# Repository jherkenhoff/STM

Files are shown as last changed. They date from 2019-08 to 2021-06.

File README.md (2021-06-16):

# Scanning tunneling microscope

# Table of Contents
- [Mechanics](#mechanics)
  - [Vibration Isolation](#vibration-isolation)
    - [Characterization Measurements](#vibration-characterization-measurements)
  - [Piezo Scanner](#piezo-scanner)
  - [Scan Head Assembly](#scan-head-assembly)
- [Electronics](#electronics)
  - [Power Supply](#power-supply)
  - [Mainboard](#mainboard)
  - [Tunneling Amp](#tunneling-amp)
  - [Base and Head Interconnect](#interconnects)
- [Software](#software)
  - [PRU Firmware](#pru-firmware)
  - [Kernel Driver](#kernel-driver)
  - [Webapp](#webapp)
    - [Backend](#backend)
    - [Frontend](#frontend)
- [References](#references)

# Mechanics

### Vibration Isolation

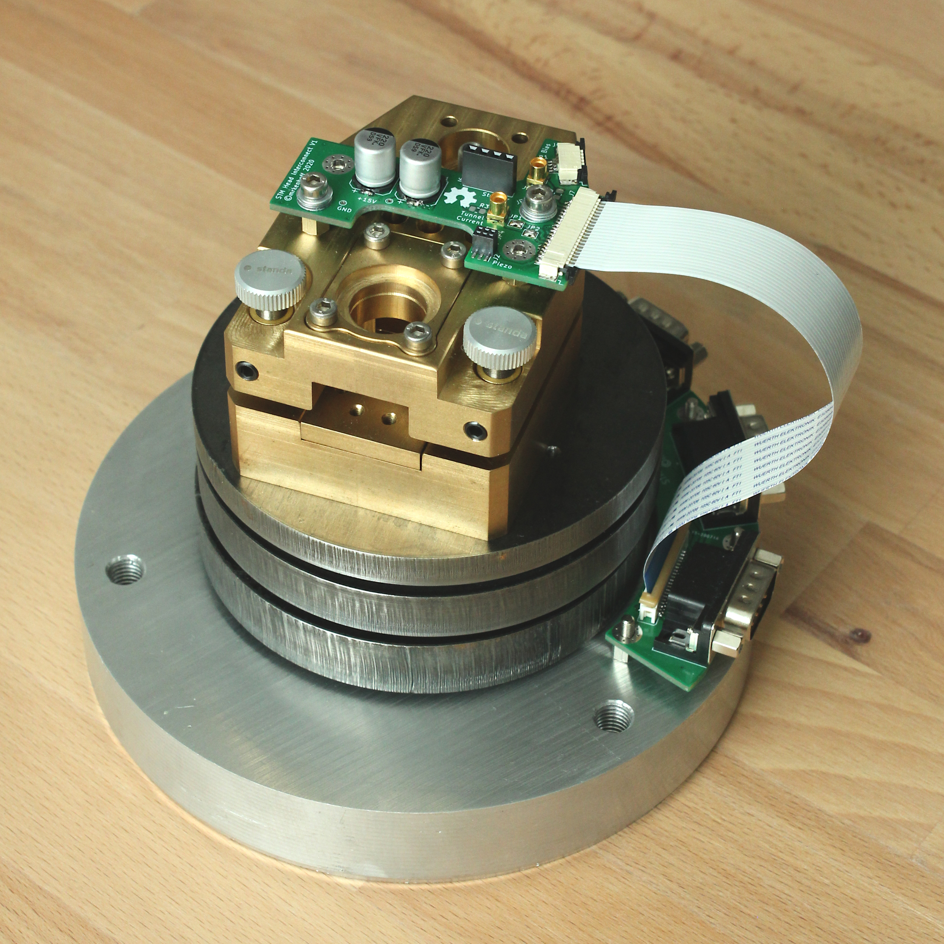
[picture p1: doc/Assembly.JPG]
STM Assembly


Mechanical vibrations present a major difficulty in scanning probe microscopy, as they can interfere with the very small (resolutions of a few 0.1 nm are not uncommon [1]) scanning movements of the tip, leading to a distorted image. Even worse, large mechanical vibrations can cause the scanning tip, which is usually positioned only a few Angstrom above the sample surface [2], to crash into the sample.

Unfortunately, there are many sources for mechanical vibrations: Driving cars, peoples walking around, wind blowing on the walls of your house and the subtle, but omnipresent seismic activity of the earth, just to name a few.
Especially since I'm living in a big City, good isolation of vibrations from the scanning head was essential for this build.
To accomplish this, I used a stack of steel plates, separated using pieces of Viton o-rings.
Viton was used, as it is reported to have a high damping coefficient, making it particularly usefull for vibration isolation [3]. This tower of heavy masses and Viton "springs/dampers" can be described as a set of coupled harmonic oscillators, which (if tuned correctly) provide an efficient way of decoupling mechanical vibrations. The vibration isolation should be designed to have the smallest possible resonance frequency (usually in the range of a couple Hz [*todo: citation*]), resulting in the desired attenuation of vibrations in the higher frequency range. The scanning head itself, which is mounted on the topmost steel plate, is designed to have the largest possible resonance frequency. This will guarantee, that any low frequency component that couple through the vibration isolation assembly will only shake the scanning head as a whole, and not influence the relative position between the tip and the probe surface.

The figure above depicts an aluminium baseplate (150 mm diameter, 25 mm thickness), the stack of steel plates and viton o-rings, and the scanning head. The steel plates have a diameter of 100 mm and have an decreasing thickness of 15 mm, 12 mm and 8 mm towards the top. I do have some spare plates lying around, so I will definately try out some other configurations as well. The plates are lasercut - hence the terrible surface finish. I might clean them up on a lathe if I can get my hands on one at some point...
The complete depicted assembly can optionally be hung from some kind of support structure using steel springs or elastic rope to add another stage of vibration isolation. Since the baseplate is made of aluminium, additional eddy-current damping can be applied if needed.

#### Characterization Measurements
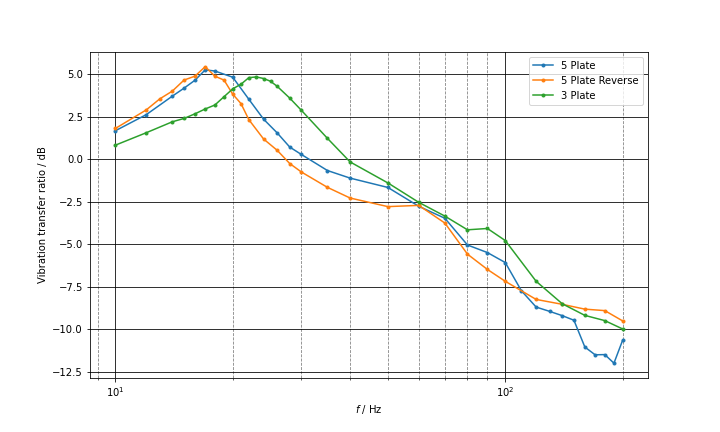
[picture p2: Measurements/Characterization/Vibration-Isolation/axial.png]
Axial vibration isolation measurement


### Piezo Scanner
Most professional scanning tunneling microscopes make use of piezo tube scanners. Due to their high rigidity (high resonance frequency) and exceptional linearity they are ideally suited for that task. Unfortunately they can cost up to several hundred euros and it's not easy to find a distributor who sells these things to individuals in the first place.

Fortunately, there is an alternative for the expensive piezo tube scanners: Flat piezo disks, commonly used as acoustic transducers in all kinds of electronic devices, can be modified to provide the desired x/y/z scanning motion. For that, the top electrode of the piezo must be cut into four segments, which will be individually controlled using four control voltages. A small standoff is glued to the bottom side of the piezo disk, to which the scanning probe tip is attached.
Depending on the applied voltages, the piezo disk will bend and warp, resulting in a translation of the scanning probe tip.
The idea and the first successfull realization for this "unimorph disk scanner" was published by John Alexander in his great STM Project.
Since then, this approach has been successfully used in numerous other low-cost STM projects, as these devices are really cheap (less than 1€ per part) and sold by all major electronics distributors.
The downside of this approach is its low mechanical rigidity, resulting in a lower resonance frequency compared to professional piezo tube scanners. Therefore the achievable scan speed is somewhat limited and the piezo scanner is more sensitive to mechanical vibrations.
These are limitations I am willing to accept, as it saves me a lot of money, while still providing great results.

I used a 20 mm piezo disk and carefully cut the upper electrode into four segments using a scalpel. The upper electrode is commonly made of deposited silver which can be scraped off with medium force. However, care must be taken not to cut/scrape too deep into the piezo crystal itself, as it might get damaged.
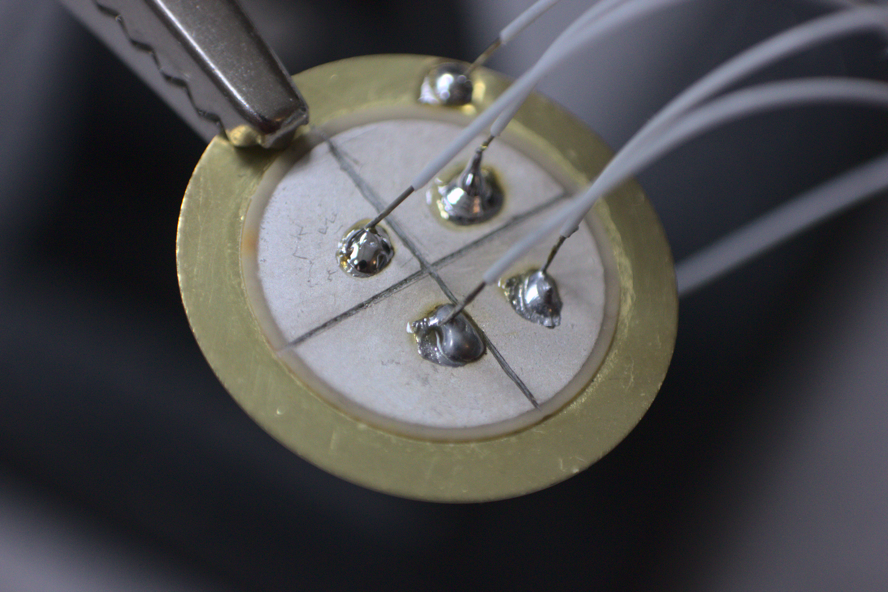
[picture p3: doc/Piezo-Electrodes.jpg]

I attached thin enameled copper wires to the electrodes ~~using conducting epoxy (MG Chemicals 9410)~~ using solder. Tthere is the risk of depolarizing the piezo crystal when applying too much heat, but luckily my piezo survived. The copper wires are attached to a miniature 2x6 pin header, which connects to the head interconnect PCB.

A 10mm ceramic standoff (Essentra Components CER-3) is glued to the bottom of the piezo element, translating the "warping motion" of the flat piezo disk into a translational motion of the scanning probe tip, which in turn is inserted into a precision pin socket glued to the other side of the ceramic standof. Ceramic was chosen for its very high resistivity, resulting in low leakage of the tunneling current.
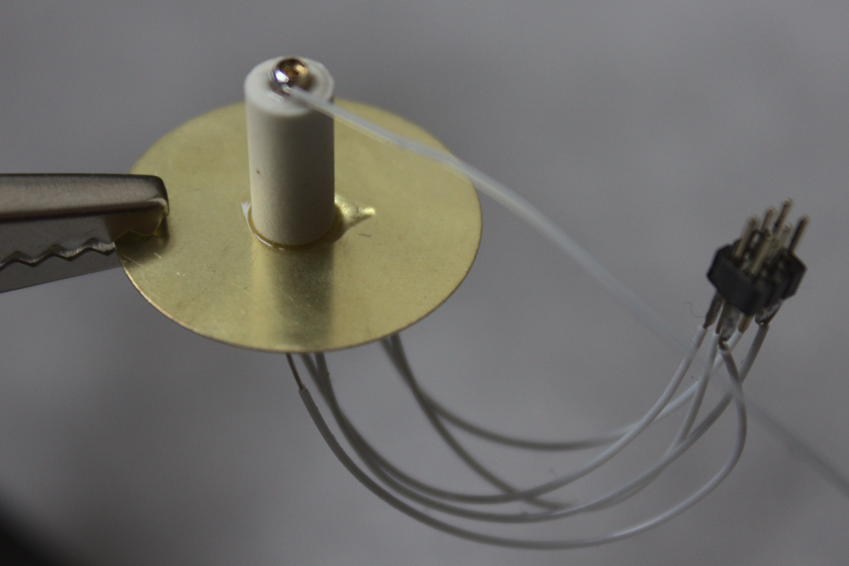
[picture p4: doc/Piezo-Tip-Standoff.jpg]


The piezo disk is placed in a brass mounting plate and is held down using a small 3D printed plate when screwed into the scanning head. I decided against mounting the piezo directly onto the scanning head in order to stay flexible and be able to experiment with different piezo scanners, by simply swapping out the whole brass-plate assembly.
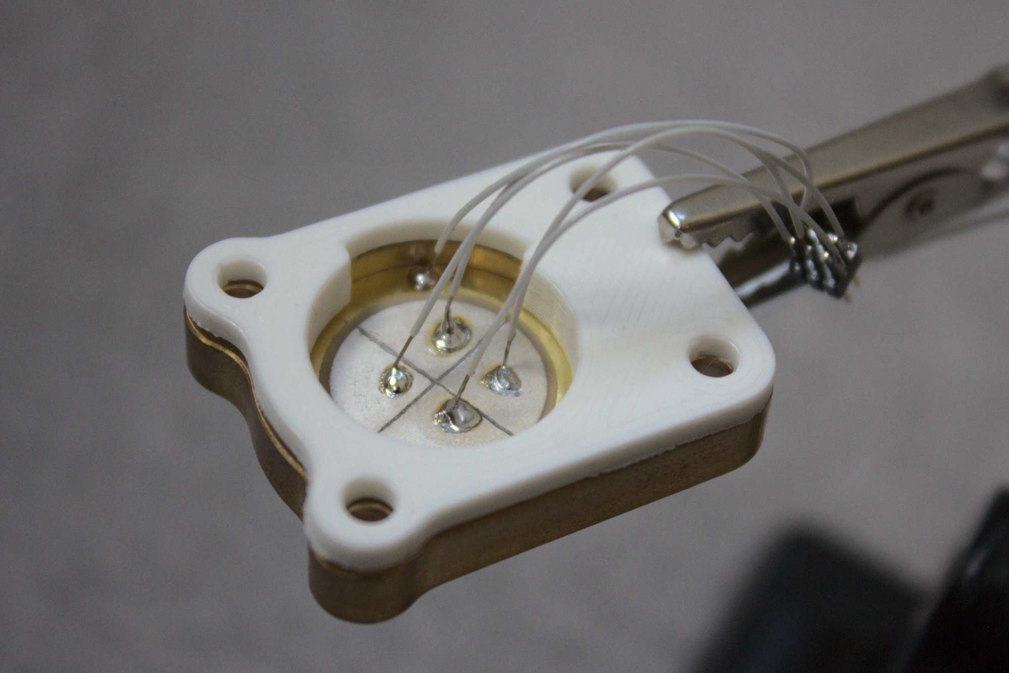
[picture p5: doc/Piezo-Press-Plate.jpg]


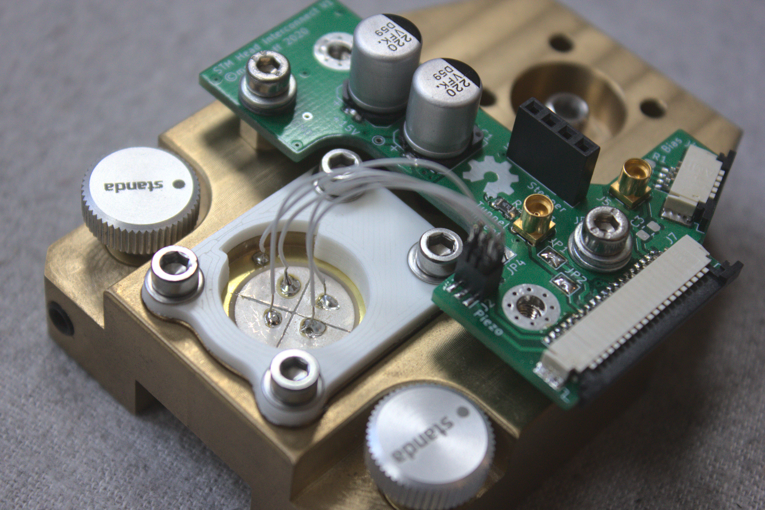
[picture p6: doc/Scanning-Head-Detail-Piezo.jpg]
Scanning head assembly


### Scan Head Assembly
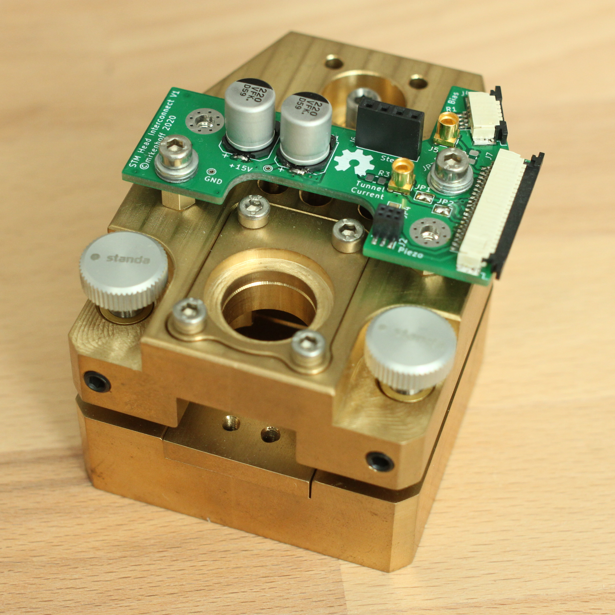
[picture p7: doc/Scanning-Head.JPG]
Scanning head assembly


The scan head assembly is the central piece of the STM. It's the place where the piezo scanner, including the scanning probe tip, and the material to be imaged are mounted and brought together, and thus contributes directly the achievable image quality.

All parts of the scan head assembly have been machined out of brass using a CNC mill. The choice of material is

- Lowest possible thermal expansion coefficient to reduce gradient artifacts due to thermal fluctuations.
- Highest possible stiffness in order to achieve a high mechanical resonance frequency of the scan head assembly.
- The material must not cost a fortune and should be relatively easy to machine without highly specializied equipment.

# Electronics
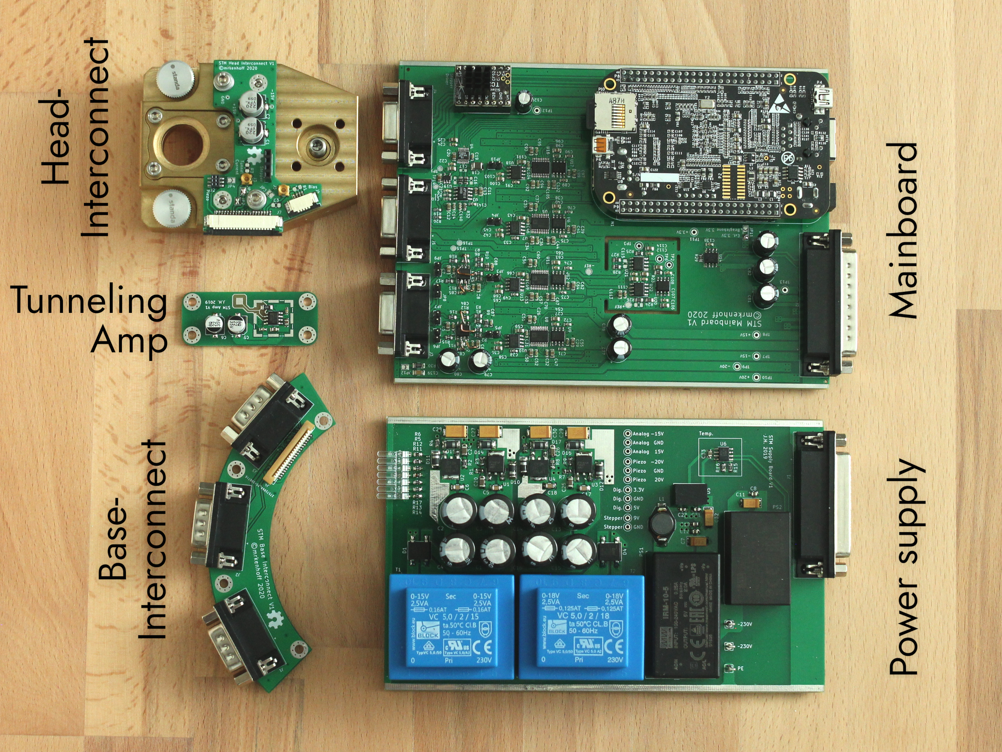
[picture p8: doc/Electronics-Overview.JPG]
Electronics overview


### Power Supply

- **Analog +/- 15 V:** Supply for DACs, ADC and tunneling amp
- **Piezo +/- 20 V:** Supply for piezo driver amplifiers
- **Digital 5 V:** Beaglebone supply
- **Digital 3.3 V:** Digital interfaces (DACs, ADC) and supply for temperature sensor
- **Stepper 9 V:** Supply for stepper motor driver

### Mainboard

### Tunneling Amp

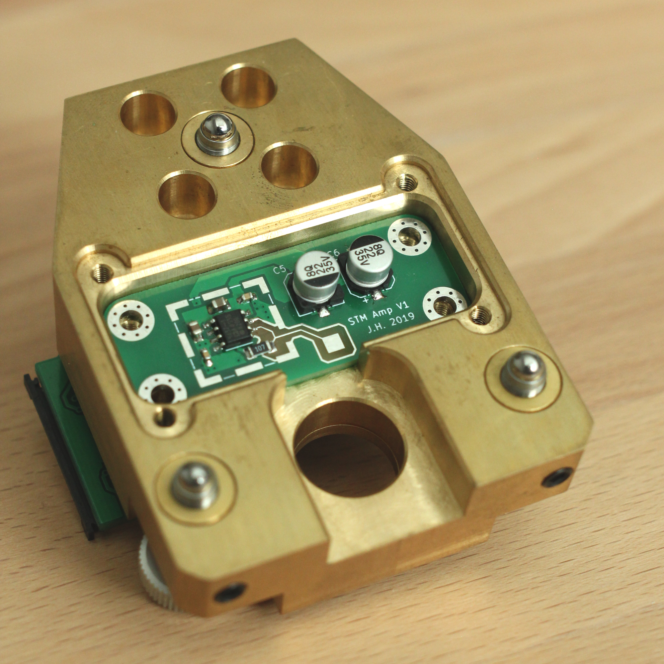
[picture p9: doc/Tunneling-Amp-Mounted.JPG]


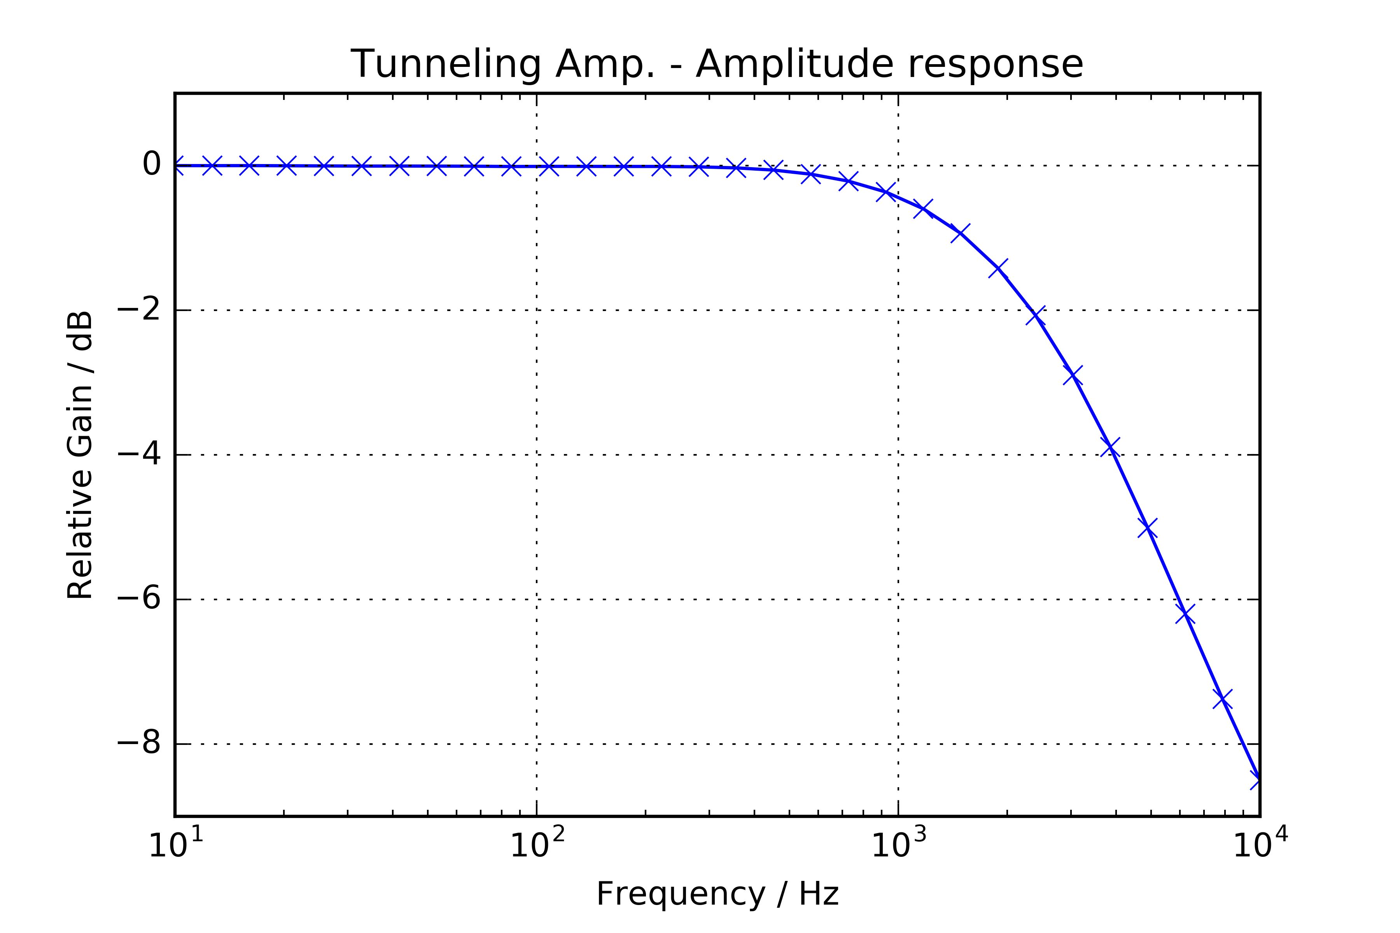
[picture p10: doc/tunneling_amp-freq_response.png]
tunneling-amp-freq-response


### Base and Head Interconnect

# Software

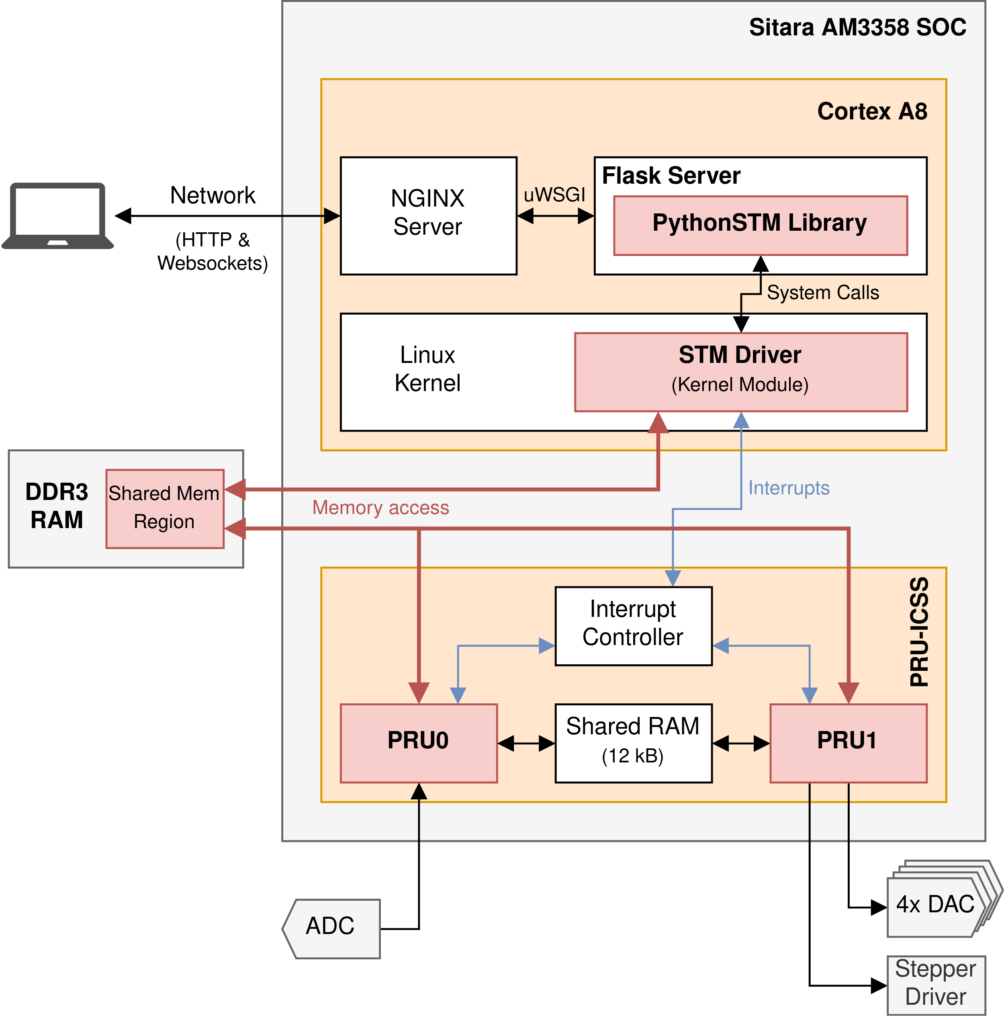
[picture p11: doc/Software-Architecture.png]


### PRU Firmware
### Kernel Driver
### Webapp
#### Backend
#### Frontend

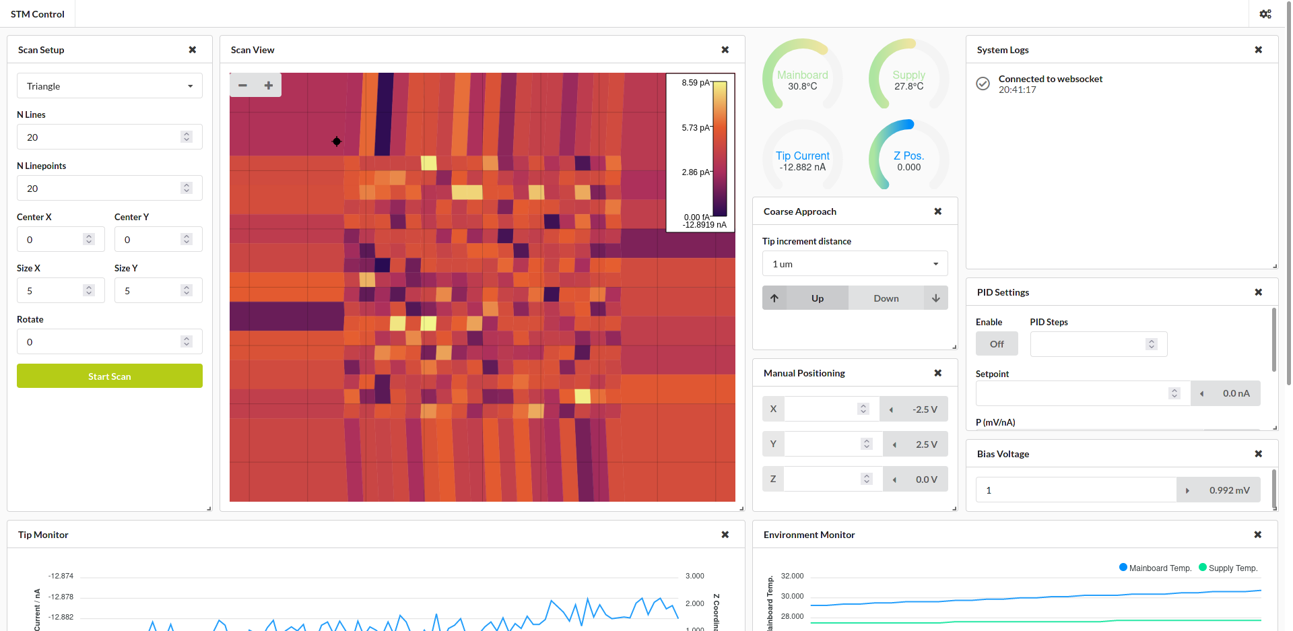
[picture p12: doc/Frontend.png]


# References

- [1] C. Bai (2000). Scanning tunneling microscopy and its applications. New York: Springer Verlag. ISBN 978-3-540-65715-6.
- [2] C. Julian Chen (1993). Introduction to Scanning Tunneling Microscopy (PDF). Oxford University Press. ISBN 978-0-19-507150-4.
- [3] Oliva, Ai & Aguilar, Marilyn & Sosa, Victor. (1999). Low- and high-frequency vibration isolation for scanning probe microscopy. Measurement Science and Technology. 9. 383. 10.1088/0957-0233/9/3/011.

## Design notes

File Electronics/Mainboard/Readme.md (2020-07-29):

## Changes for version 2:

- Correct polarity of electrolyte capacitors
- Remove pin DAC_MISO (Fails to boot: https://github.com/beagleboard/beaglebone-black/wiki/System-Reference-Manual#boot-configuration)
- Change + and - Pins of Z+X / Z-X / Z+Y / Z-Y OP Amps

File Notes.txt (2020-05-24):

# ADC Selection

Architecture: SAR, because Delta-Sigma has a large latency ->  Bad control loop behaviour

# Supply

+/- 15V Tunneling Amp and Analog Circuitry
        10 mA Tunneling Amp
+/- 20V Piezo driver
5V/3,3V Digital supply
???     Stepper driver voltage

LM75 Temperature Sensors
  - One near the transformators
  - One near the regulators
  - ADC Board
  - DAC Board
  - DAC Board OP section

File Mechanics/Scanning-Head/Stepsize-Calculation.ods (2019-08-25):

Step angle | 1.8 | °
Gear ratio | 27
Screw pitch | 0.24 | mm/rev
Lever ratio | 16
Tip step size | 2.77777777777778 | nm/step

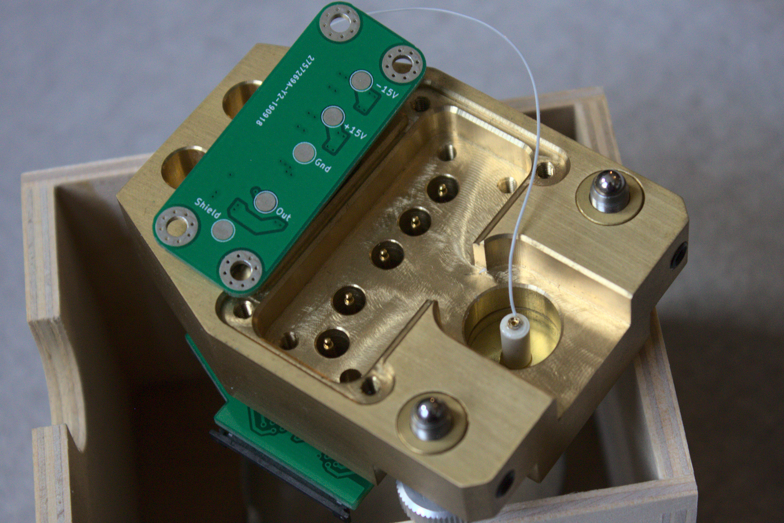
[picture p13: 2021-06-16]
doc/Scanning-Head-Amp.jpg

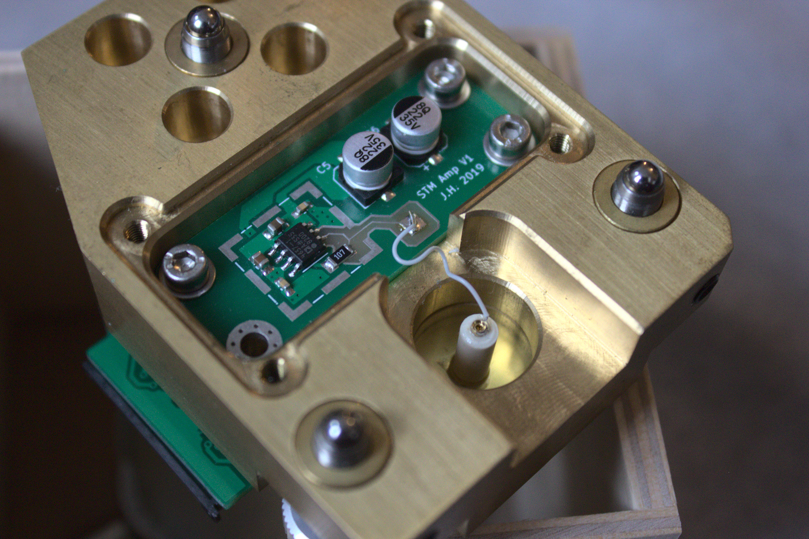
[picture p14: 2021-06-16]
doc/Scanning-Head-Amp-Mounted.jpg

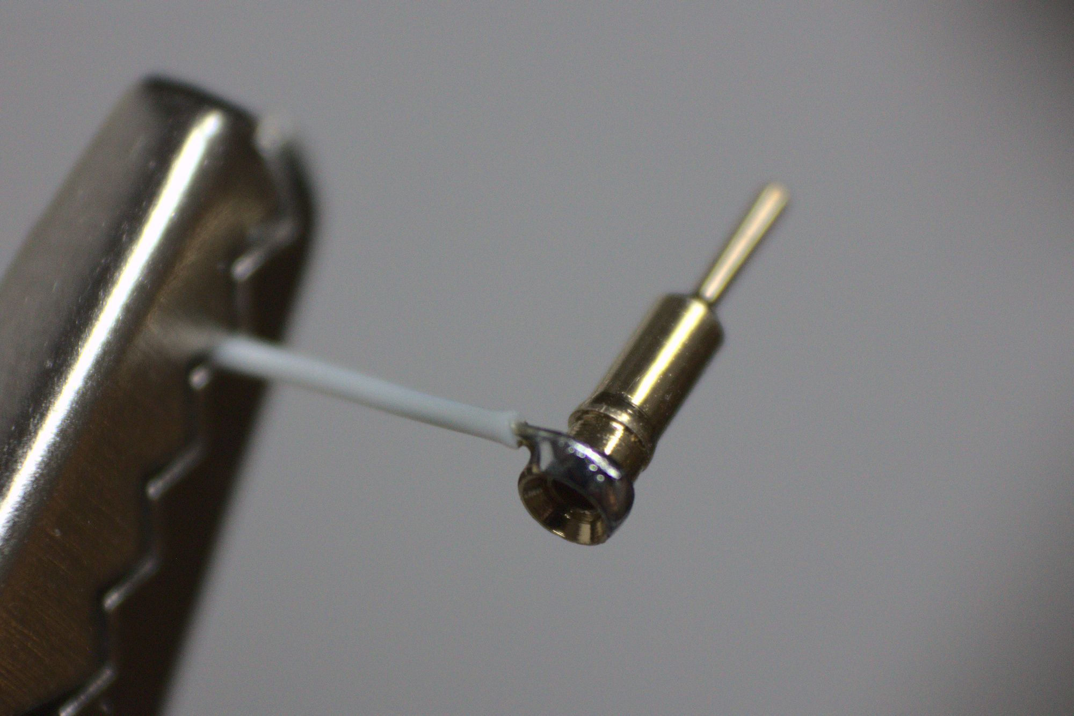
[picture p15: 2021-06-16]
doc/Pin-Socket.jpg

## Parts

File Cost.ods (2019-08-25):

Bezeichnung | Anzahl | Einzelpreis | Versandkosten | Gesamt
Mechanik
Schrittmotor | 1 | 34.75 | 4 | 38.75
Einstellschrauben | 1 | 68 | 0 | 68
Messing | 1 | 30 | 10 | 40
Aluminium | 1 | 20 | 0 | 20
Plastik | 1 | 15 | 0 | 15
Stahl | 1 |  |  | 0
Viton | 1 | 14 | 0 | 14
 |  |  |  | 0
 |  |  |  | 0
Elektronik
Piezo | 3 | 3 | 0 | 9
Tunnel OPA | 2 | 10 | 0 | 20
DAC | 5 | 10 | 0 | 50
ADC | 1 | 15 | 0 | 15
 |  |  |  | 0
 |  |  |  | 0
 |  |  |  | 0
PCBs | 1 | 20 | 6 | 26
 |  |  |  | 0
 |  |  |  | 0
 |  |  | Gesamt | 315.75

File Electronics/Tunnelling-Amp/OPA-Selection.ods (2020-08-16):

Hersteller | Typ | Input bias |  | GBW | Voltage Noise | Current Noise | Offset Voltage (Typ) |  | In. Volt. Drift | Supply | Preis
 |  | pA | pA | MHz | nV/√Hz | fA/√Hz | µV |  | µV / °C | V | EUR
 |  | 25°C | Tmin – Tmax |  | 1 kHz |  | 25°C | Tmin – Tmax
TI | LMC6081AI | 0.01 | 4 | 1.3 | 22 |  | 350 | 800 | 1 | 16 | 2.5
TI | LMC6001 | 0.01 | 2 | 1.3 | 22 |  | 700 | 1000 | 2.5 | 16 | 15
AD | ADA4637-1B | 1 | 2000 | 80 | 6 | 1.6 | 200 | 400 | 1 | 36 | 10
TI | OPA602BP | 1 | 20 | 6.2 | 13 | 0.6 | 500 | 750 | 3 | 36 | 15 | Nur DIP!
 | OPA637AP | 2 | 2000 | 80 | 5.6 | 2.5 | 280 | / | 2.5 | 36 | 23
 | OPA637BP | 1 | 1000 | 80 | 5.2 | 1.6 | 100 | / | 0.8 | 36 | 30
 | OPA124UA | 0.5 | 2 |  | 8 | 0.5 | 150 | 500 | 2 | 36 | 11
 | ADA4530-1 | 0.02 | 0.25 | 2 | 16 | 0.07 | 8 | 300 | 0.13 | 16 | 22
 | OPA828 | 1 | 400 | 45 | 4 | 1.2 | 50 | 400 | 0.3 | 40 | 7
 | OPA129 | 0.03 | 30 | 1 | 17 | 0.1 | 500
 |  |  |  |  |  | GBW | 80 | MHz
 |  |  |  |  |  | R | 100 | Mohm
 |  |  |  |  |  | C | 10 | pF
 |  |  |  |  |  | Bandwidth | 112.8 | kHz
 |  |  |  |  |  | Quelle: | http://www.ti.com/lit/an/sboa122/sboa122.pdf

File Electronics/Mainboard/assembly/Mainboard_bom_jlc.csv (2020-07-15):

Comment | Designator | Footprint | LCSC Part #
2u2 | C20,C21 | C_0805_2012Metric_Pad1.15x1.40mm_HandSolder | C49217
220p | C83,C84,C85,C86,C88,C87 | C_0603_1608Metric_Pad1.05x0.95mm_HandSolder | C1603
10p | C91,C89,C90,C49,C73,C74,C33,C75,C76,C28,C71,C72 | C_0603_1608Metric_Pad1.05x0.95mm_HandSolder | C1634
10u | C106,C109,C118,C119,C113,C114,C102,C92,C93,C96,C97,C100,C101,C5,C6,C7,C8,C67,C53,C56,C61,C62,C65,C66,C44,C34,C35,C38,C39,C42,C43,C47,C50,C51,C54,C55,C58,C59,C11,C12,C25,C23 | C_0805_2012Metric_Pad1.15x1.40mm_HandSolder | C15850
100n | C138,C108,C107,C111,C112,C117,C116,C94,C95,C99,C98,C103,C104,C105,C1,C2,C3,C4,C57,C60,C64,C63,C68,C69,C70,C36,C37,C41,C40,C45,C46,C48,C52,C26,C29,C27,C30,C31,C32,C13,C14,C19,C22,C24 | C_0603_1608Metric_Pad1.05x0.95mm_HandSolder | C14663
100n | C139 | C_1206_3216Metric_Pad1.42x1.75mm_HandSolder | C24497
1n | C140,C9 | C_0603_1608Metric_Pad1.05x0.95mm_HandSolder | C1588
680p | C141,C10 | C_0603_1608Metric_Pad1.05x0.95mm_HandSolder | C1630
3k3 | R13,R14,R7,R8,R5,R6,R10,R1,R2,R11,R12,R3,R4,R9 | R_0805_2012Metric | C26010
49R9 | R18,R17,R16,R15 | R_0805_2012Metric | C17720
560R | R19,R20 | R_0603_1608Metric_Pad1.05x0.95mm_HandSolder | C23204
0R | R22,R21 | R_0805_2012Metric | C17477
1k | R23,R24,R26,R25,R27,R28 | R_0805_2012Metric | C17513
4k7 | R29 | R_0805_2012Metric | C17673
1M2 | R30 | R_1206_3216Metric_Pad1.42x1.75mm_HandSolder | C22107
1k | R32,R31 | R_0603_1608Metric_Pad1.05x0.95mm_HandSolder | C21190

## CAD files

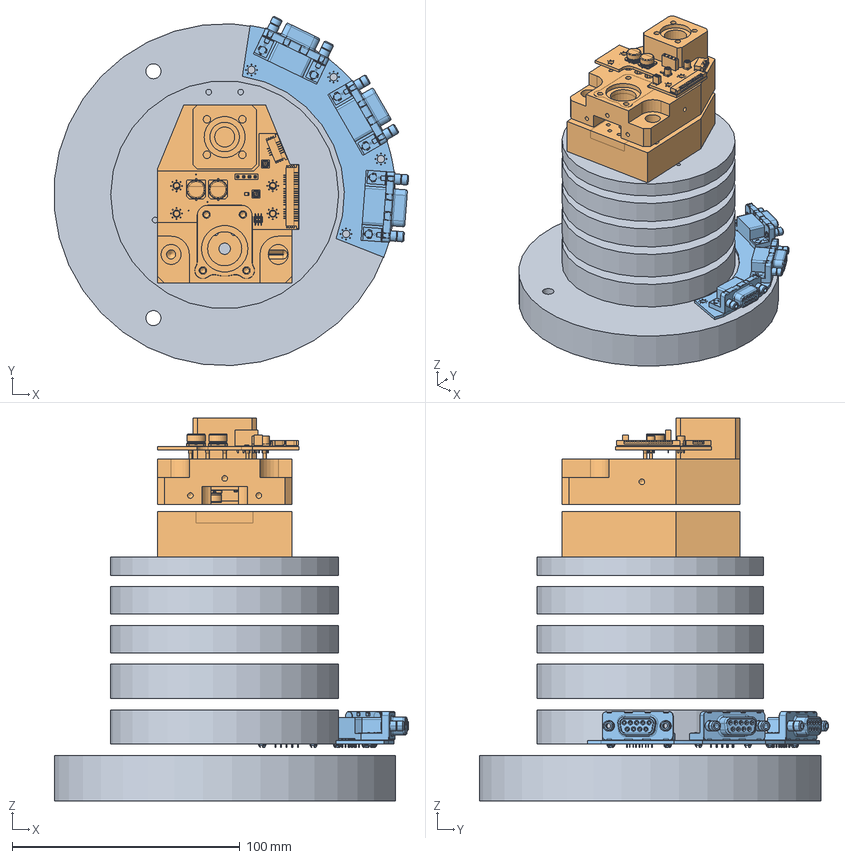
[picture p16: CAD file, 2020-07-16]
Mechanics/Assembly.FCStd
155.4 x 153.1 x 168.0 mm
Vibration-Isolation_001
Scanning-Head-Assembly_001
Base-Interconnect1_001

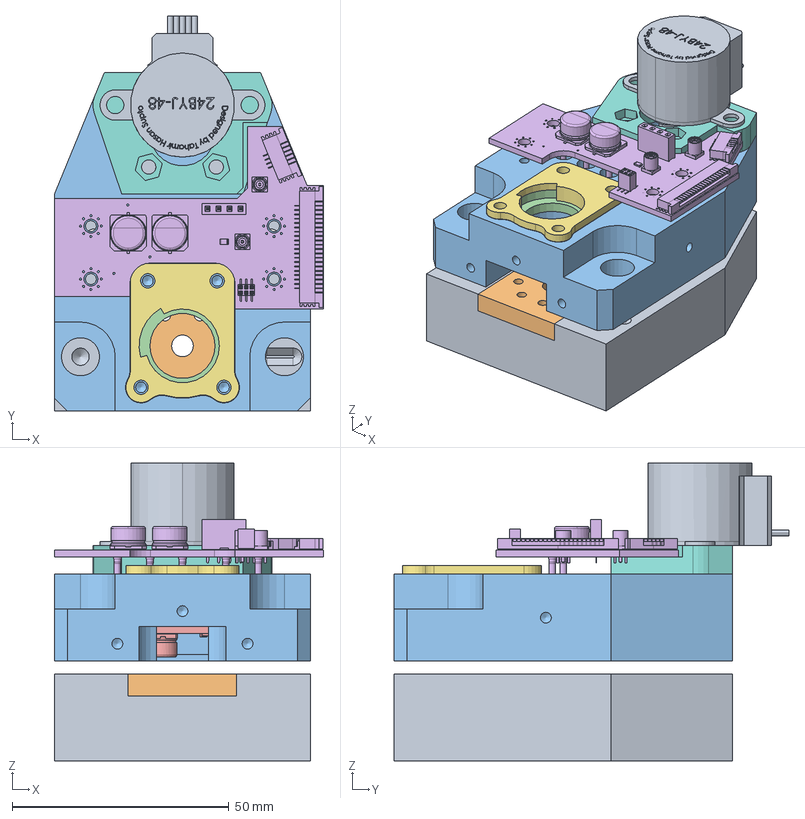
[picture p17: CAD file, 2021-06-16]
Mechanics/Scanning-Head/Scanning-Head-Assembly.FCStd
62.0 x 91.0 x 68.6 mm
Lower-Plate_001
Probe-Holder_001
Upper-Plate_001
Tip-Holder_001
Tunnelling-Amp1_001
Head-Interconnect1_001
Piezo-Press-Plate_001
Motor-Adapter_001
stepper-24BYJ-481_001

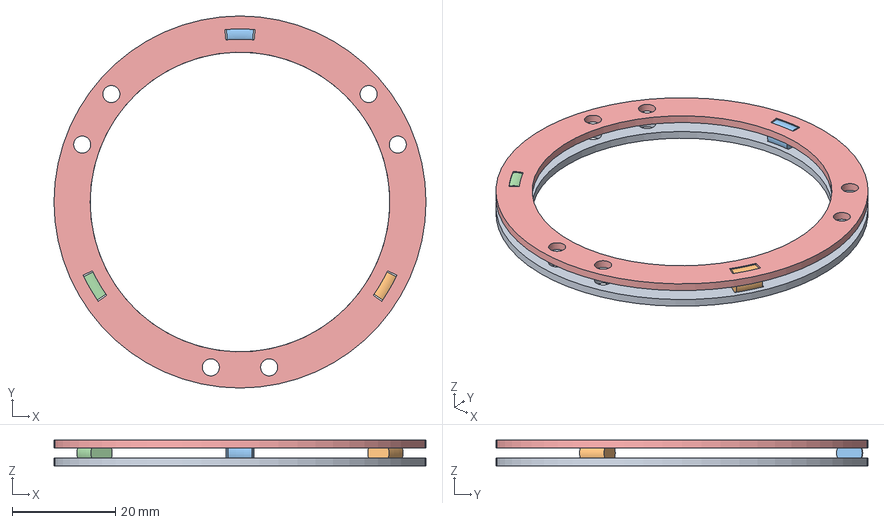
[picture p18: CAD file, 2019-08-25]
Mechanics/Vibration-Isolation/Viton-Assembly.FCStd
72.0 x 72.0 x 5.00 mm
Viton-Fixture_001
Viton_001
Viton_002
Viton_003
Viton-Fixture_002

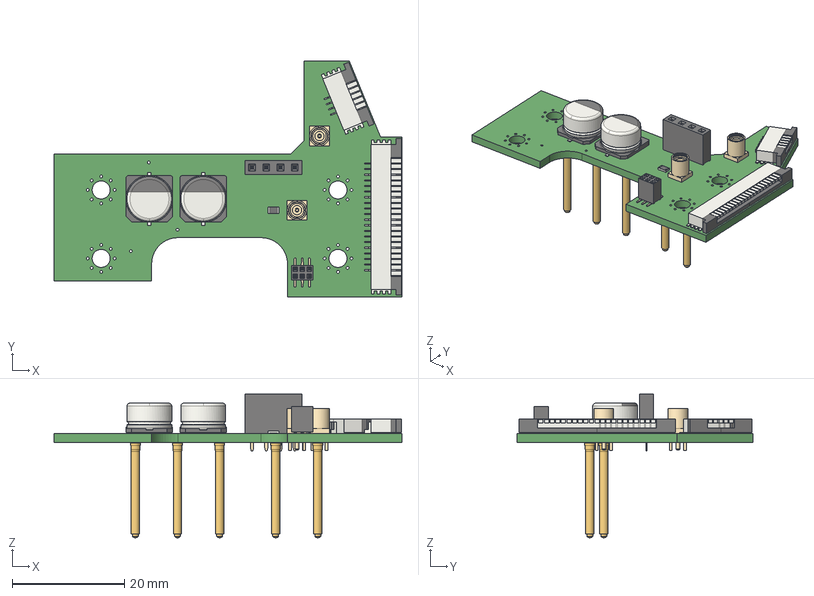
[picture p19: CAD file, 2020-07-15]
Electronics/Head-Interconnect/Head-Interconnect.step
62.0 x 42.1 x 25.6 mm

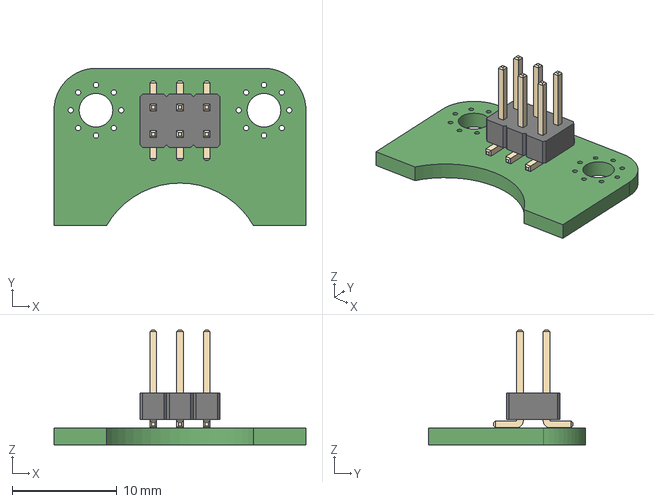
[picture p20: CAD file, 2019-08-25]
Electronics/Piezo-Connector/Piezo-Connector.step
24.0 x 15.0 x 11.0 mm

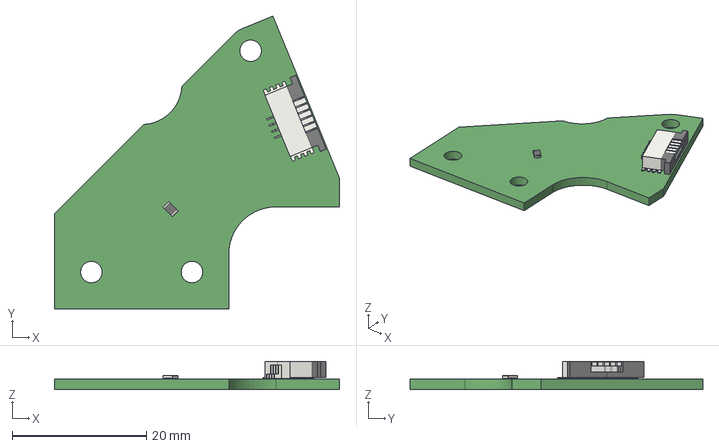
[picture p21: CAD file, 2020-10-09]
Electronics/Sample-Bias-Interconnect/Sample-Bias-Interconnect.step
42.5 x 43.7 x 4.21 mm

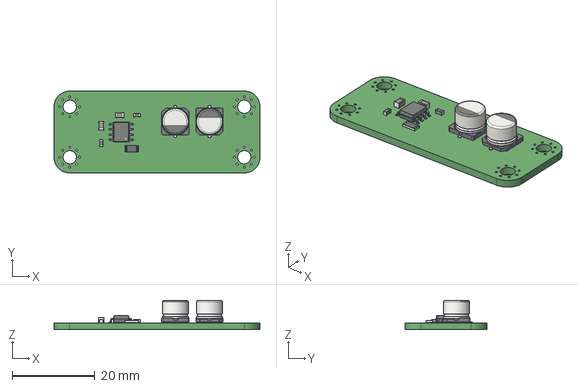
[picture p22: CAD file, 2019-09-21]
Electronics/Tunnelling-Amp/Tunnelling-Amp.step
49.8 x 19.8 x 7.05 mm

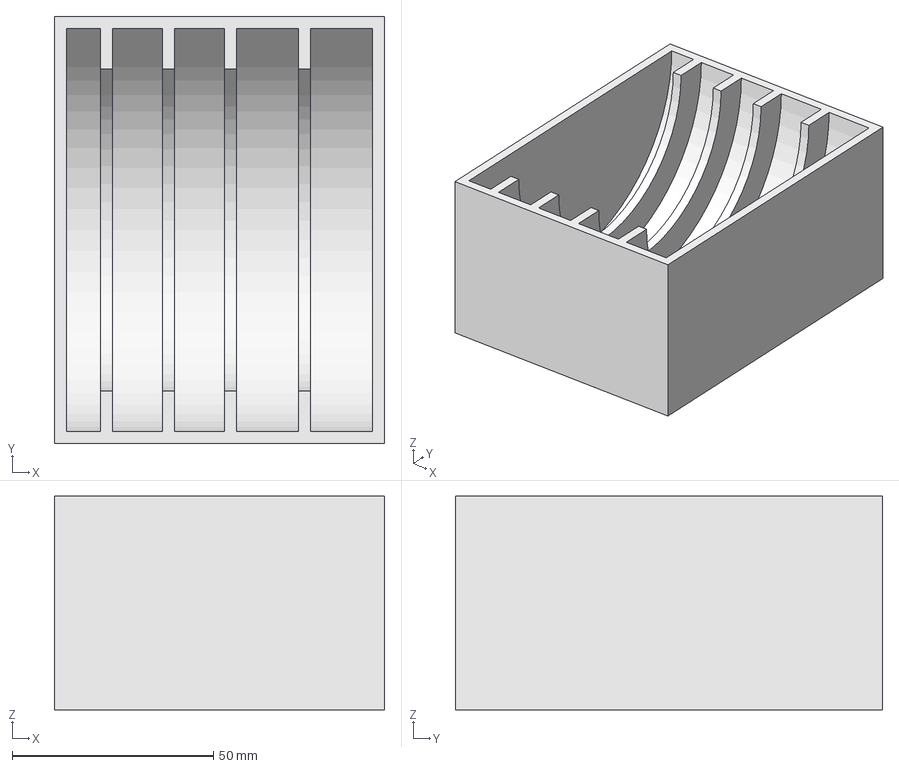
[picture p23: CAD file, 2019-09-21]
Mechanics/Casing/Plates-Case.FCStd
82.0 x 106.0 x 53.0 mm

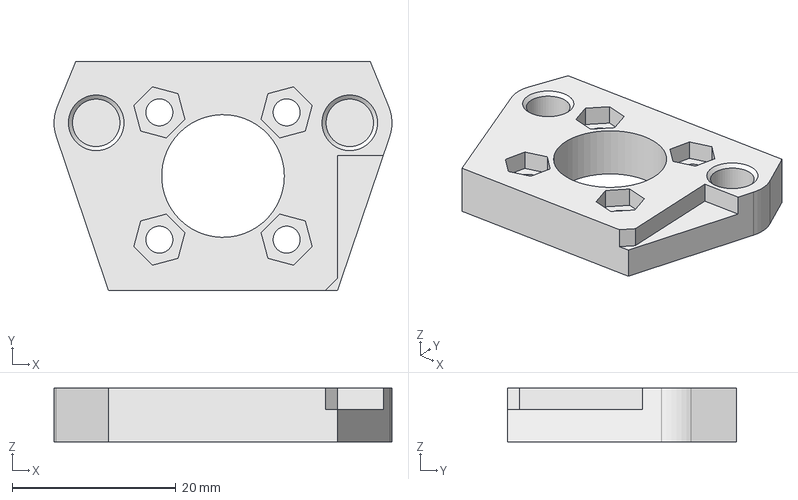
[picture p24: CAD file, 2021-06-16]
Mechanics/Scanning-Head/Motor-Adapter.FCStd
41.3 x 28.0 x 6.60 mm

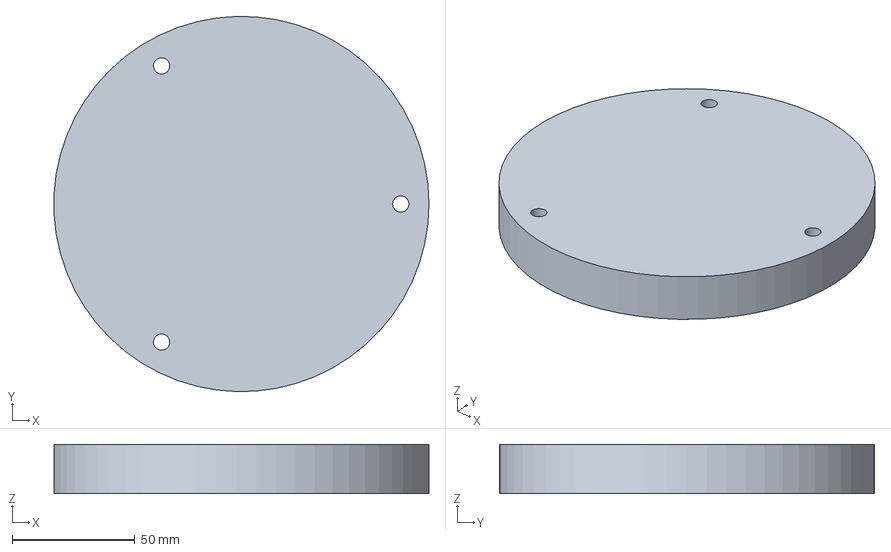
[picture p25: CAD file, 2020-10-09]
Mechanics/Vibration-Isolation/Base-Plate.FCStd
152.9 x 152.9 x 20.0 mm

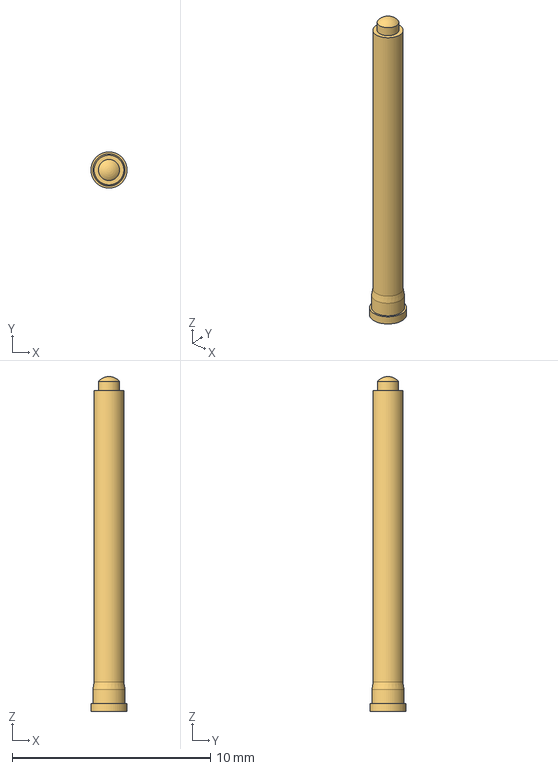
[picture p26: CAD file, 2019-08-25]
Electronics/Head-Interconnect/0905-0-15-20-75-14-11-0.step
1.83 x 1.83 x 16.9 mm

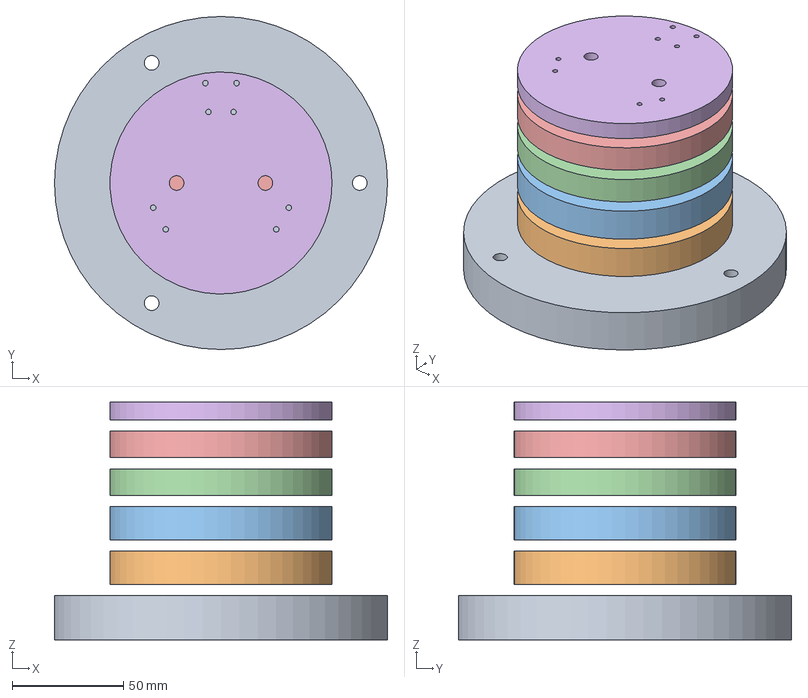
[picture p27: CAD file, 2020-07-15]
Mechanics/Vibration-Isolation/Vibration-Isolation.FCStd
150.0 x 150.0 x 107.0 mm
Base-Plate_001
Plate_15_001
Plate_15_002
Plate_12_001
Plate_12_002
Plate_8_001

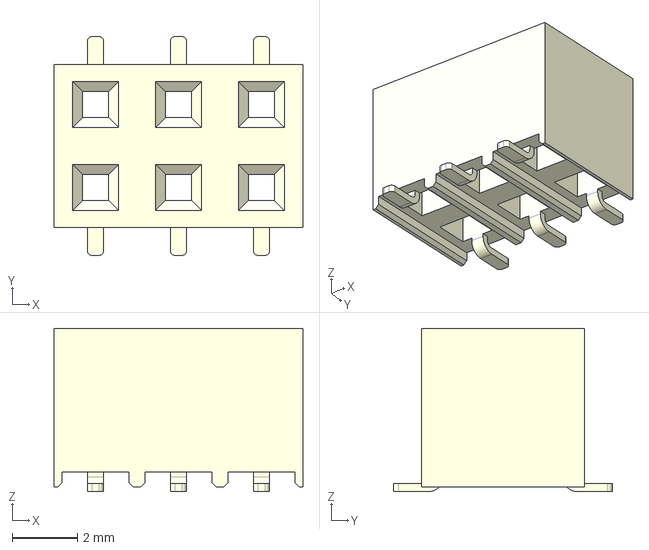
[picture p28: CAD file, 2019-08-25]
Electronics/Head-Interconnect/board-to-board.step
7.62 x 6.70 x 5.00 mm

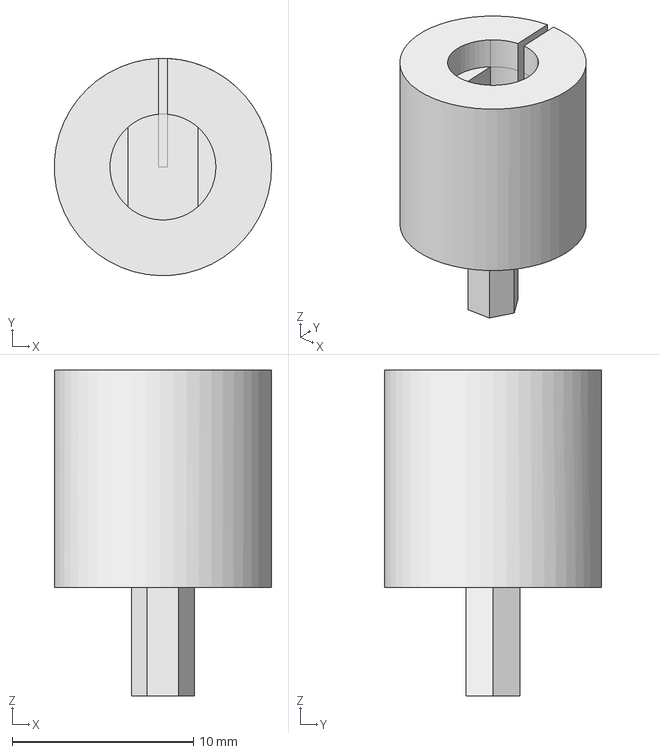
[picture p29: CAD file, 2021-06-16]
Mechanics/Scanning-Head/Motor-Axle-Adapter.FCStd
12.0 x 12.0 x 18.0 mm

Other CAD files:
Mechanics/Scanning-Head/Scanning-Head-Assembly2.FCStd
Mechanics/Vibration-Isolation/Plate_15.FCStd
Electronics/Head-Interconnect/sma.stp
Mechanics/Scanning-Head/Piezo-Press-Plate.FCStd
Electronics/Head-Interconnect/0905-0-15-20-75-14-11-0.FCStd
Electronics/Head-Interconnect/0905-0-15-20-75-14-11-0.stl
Mechanics/Scanning-Head/Amp-Plate.FCStd
Mechanics/Scanning-Head/Lower-Plate-PCB-Outline.dxf
Mechanics/Scanning-Head/Lower-Plate.FCStd
Mechanics/Scanning-Head/Lower-Plate.dxf
Mechanics/Scanning-Head/Motor-Adapter.stl
Mechanics/Scanning-Head/Motor-Axle-Adapter.stl
Mechanics/Scanning-Head/Piezo-Press-Plate.stl
Mechanics/Scanning-Head/Piezo.FCStd
Mechanics/Scanning-Head/Probe-Holder.FCStd
Mechanics/Scanning-Head/Tip-Holder.FCStd
Mechanics/Scanning-Head/Upper-Plate.FCStd
Mechanics/Vibration-Isolation/Plate_12.FCStd
Mechanics/Vibration-Isolation/Plate_8.FCStd
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

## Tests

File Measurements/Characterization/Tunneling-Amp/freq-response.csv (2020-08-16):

freq | H
9.89530235528946 | -1.05493231e-04
12.689270079135895 | -7.48342915e-04
16.065314412117004 | 0.00000000e+00
20.372681319713593 | -2.09002341e-03
25.84420144557953 | -4.37639170e-03
32.82912075519562 | -6.93168062e-03
41.676685214042664 | -6.10499080e-03
52.96897143125534 | -7.06103981e-03
67.17164069414139 | -8.42543563e-03
85.21601557731628 | -1.25753462e-02
108.14983397722244 | -1.06812066e-02
137.37007975578308 | -1.10707435e-02
174.27373677492142 | -1.17969067e-02
221.18911147117615 | -1.19176100e-02
280.67734092473984 | -1.70530179e-02
356.1144694685936 | -3.16322065e-02
451.92427933216095 | -6.17012819e-02
573.5782906413078 | -1.18662364e-01
727.8285920619965 | -2.14524285e-01
923.6391633749008 | -3.64948022e-01
1172.0694601535797 | -5.96633496e-01
1487.3221516609192 | -9.36708381e-01
1887.3251974582672 | -1.41919255e+00
2395.01241594553 | -2.06915719e+00
3039.1383916139603 | -2.89812281e+00
3856.6067814826965 | -3.89305048e+00
4893.867298960686 | -5.01206120e+00
6210.058927536011 | -6.19650023e+00
7880.3859651088715 | -7.37896665e+00
9999.959729611874 | -8.49963993e+00

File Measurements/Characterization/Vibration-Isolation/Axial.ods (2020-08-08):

Setup: | Big, Big, Medium, Medium, Small
f | CH1 | CH2 | Ratio | dB
10 | 8.5 | 12.5 | 1.47058823529412 | 1.67491087293764
12 | 11.7 | 21.4 | 1.82905982905983 | 2.62227911603029
14 | 11.7 | 27.5 | 2.35042735042735 | 3.71146832084101
15 | 11 | 28.8 | 2.61818181818182 | 4.17999802601006
16 | 10.6 | 30.9 | 2.91509433962264 | 4.64652614160064
17 | 10.4 | 34.9 | 3.35576923076923 | 5.257920876604
18 | 8.87 | 29.3 | 3.3032694475761 | 5.18944000522383
20 | 10.8 | 32.8 | 3.03703703703704 | 4.82450088224729
22 | 28.2 | 63.5 | 2.25177304964539 | 3.52524616972615
24 | 42.8 | 73.6 | 1.7196261682243 | 2.35434045324327
26 | 51.5 | 73.6 | 1.42912621359223 | 1.55070585296308
28 | 99.2 | 117 | 1.17943548387097 | 0.71674189591983
30 | 96.6 | 103 | 1.06625258799172 | 0.278600982896788
35 | 73.8 | 63.3 | 0.857723577235772 | -0.666526518056865
40 | 47.4 | 36.7 | 0.774261603375528 | -1.11112277421996
50 | 32.4 | 22.1 | 0.682098765432099 | -1.66152736521501
60 | 28 | 14.8 | 0.528571428571429 | -2.76896315947262
70 | 26.7 | 12 | 0.449438202247191 | -3.4733001531695
80 | 28.7 | 8.98 | 0.312891986062718 | -5.04605560066688
90 | 25.5 | 7.2 | 0.282352941176471 | -5.49207684002687
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

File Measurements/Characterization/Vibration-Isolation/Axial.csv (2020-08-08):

Setup: | Big, Big, Medium, Medium, Small
f | CH1 | CH2 | Ratio | dB
10 | 8.5 | 12.5 | 1.47058823529412 | 1.67491087293764
12 | 11.7 | 21.4 | 1.82905982905983 | 2.62227911603029
14 | 11.7 | 27.5 | 2.35042735042735 | 3.71146832084101
15 | 11 | 28.8 | 2.61818181818182 | 4.17999802601006
16 | 10.6 | 30.9 | 2.91509433962264 | 4.64652614160064
17 | 10.4 | 34.9 | 3.35576923076923 | 5.257920876604
18 | 8.87 | 29.3 | 3.3032694475761 | 5.18944000522383
20 | 10.8 | 32.8 | 3.03703703703704 | 4.82450088224729
22 | 28.2 | 63.5 | 2.25177304964539 | 3.52524616972615
24 | 42.8 | 73.6 | 1.7196261682243 | 2.35434045324327
26 | 51.5 | 73.6 | 1.42912621359223 | 1.55070585296308
28 | 99.2 | 117 | 1.17943548387097 | 0.71674189591983
30 | 96.6 | 103 | 1.06625258799172 | 0.278600982896788
35 | 73.8 | 63.3 | 0.857723577235772 | -0.666526518056865
40 | 47.4 | 36.7 | 0.774261603375528 | -1.11112277421996
50 | 32.4 | 22.1 | 0.682098765432099 | -1.66152736521501
60 | 28 | 14.8 | 0.528571428571429 | -2.76896315947262
70 | 26.7 | 12 | 0.449438202247191 | -3.4733001531695
80 | 28.7 | 8.98 | 0.312891986062718 | -5.04605560066688
90 | 25.5 | 7.2 | 0.282352941176471 | -5.49207684002687
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

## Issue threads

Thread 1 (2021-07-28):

Circuit problem

lky7956, 2021-07-28:
Hello
I want to ask some questions about the circuit.
Some parts on the circuit diagram are "OPT". How much does it represent? (For example, R1.R3.C3 of Head-Interconnect, etc.)

thanks

mr-kenhoff, 2021-08-02:
Hey!

The parts marked with "OPT" are optional. The footprints are printed on the PCB but I did not populate them.
Exception: R3 on Head interconnect should be a 0 Ohm Resistor (or a simple solder bridge). Sorry that I did not mark this one properly.

Cheers

mr-kenhoff, 2021-08-02:
I updated the value for R3 in the schematic. Please let me know if there are more ambiguities in the schematic.

lky7956, 2021-08-02:
Thanks for your reply.

I see these problems
C5 & C6 of Tunnelling-Amp (ELN RV2-35V220MU is 22uF,but circuit diagram shows 220uF)
https://www.reichelt.de/de/de/smd-elko-22-f-35v-2000h-eln-rv2-35v220mu-p246738.html?r=1

L1 of Supply-Board(Inductor_SMD:L_Fastron_PISN_Handsoldering,I didn’t see 3.3uF in PISN on fastron official website, only 33uF)
https://fastrongroup.com/smd-power-inductors/pisn

U3 of Supply-Board(The value should be LM317, but the value indicates 240R)

lky7956, 2021-08-02:
Thanks for your reply.

I see these problems
C5 & C6 of Tunnelling-Amp (ELN RV2-35V220MU is 22uF,but circuit diagram shows 220uF)
https://www.reichelt.de/de/de/smd-elko-22-f-35v-2000h-eln-rv2-35v220mu-p246738.html?r=1

L1 of Supply-Board(Inductor_SMD:L_Fastron_PISN_Handsoldering,I didn’t see 3.3uF in PISN on fastron official website, only 33uF)
https://fastrongroup.com/smd-power-inductors/pisn

U3 of Supply-Board(The value should be LM317, but the value indicates 240R)

mr-kenhoff, 2021-08-02:
Thanks a lot for your Help! I fixed the mentioned issues in the schematic :)

Closed 2021-09-24.

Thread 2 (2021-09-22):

how about the scanning picture/result?

123zmz123, 2021-09-22:
what  a incredible project!!! thanks for you contribution.
by the way could you pls upload more scanning result?

mr-kenhoff, 2021-09-24:
Hey!
Thanks for your message! The STM ist not producting images yet (the scan you see in the Readme is only random current noise).
I'm having trouble with unsateble tip currents, so unfortunately no possibility to do proper scans yet.

123zmz123, 2021-09-27:
Hope problem will be solved.🍀
 And I also check other similar DIY  projects, seems like they have more complex/complete Vibration isolation system, do you think the unstable tip current were caused by vibration or by the Amplifier?

Abraham76i, 2022-06-11:
> Hey! Thanks for your message! The STM ist not producting images yet (the scan you see in the Readme is only random current noise). I'm having trouble with unsateble tip currents, so unfortunately no possibility to do proper scans yet.

Have you had any progress with the STM samples? Do you think the noise problem comes from the tip and its composition?

Jeycitoo, 2022-11-14:
> t (the scan you see in the Readme is only random current noise).
**Sorry, I'm not very good at github, but where can I find the circuit diagram? (I look in the folder and manage to find the diagram)

What software are you using?

It is a very interesting project, I personally think that these DIY open source things are worth gold, thanks for sharing your work

I honestly don't know how to send you a private message, I didn't find the way on github, I would like to be able to chat with you if you allow me

Regarding the fact that it cannot produce images due to noise, it is somewhat difficult because it could be multifactorial, hopefully you can achieve it soon and share the results with us, it is impressive when you manage to see something

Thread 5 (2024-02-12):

I can't see find any scans

umartechboy, 2024-02-12:
First of all, fantastic effort, in putting your work on GitHub. The level of workmanship that you have displayed in this STM is exemplary.

We are attempting an STM here in my university and your mechanical design appears to be a promising start for this.
However, browsing the git, I couldn't find any real scans of the microscope. Were you able to complete this project? Also, have you published this work in HardwareX or a similar journal? I would love to read more about how to put all of this together.

jherkenhoff, 2024-02-13:
Dear Umar,

thanks a lot for your comment and interest.
Unfortunately I was never able to get a proper scan. However, I have to admit that this project was on standby during the last two years. But thanks to your comment I feel motivated to take the last steps towards getting the scan going :) I might continue in the next days.

Regarding your questions:

1. I use Kicad for electronics and Freecad for mechanical design. Both are open source.
2. Yes, I directly ordered the PCBs without any prior prototyping. That also meant that there were some hardware bugs, but to my surprise there were only minor problems (like a screwed up connection of two op-amps on the motherboard) that could be easily fixed. I did not run any system level simulations. I am actually quite happy with the design - but at the same time I was not able to get a proper scan, so I might be mistaken here :D I believe the main problem is the mount of the SEM tip, which is very loose and flimsy. I was able to get tunneling going, but after a few seconds it became unstable. Tuning the PID loop did not help, which is why I strongly suspect the tip mount.
3. I am quite happy with the tunneling amp. I can do some characterization measurements regarding leakage current if you are interested. This type of "leaked current guarding" is quite common in high sensitivity frontend design, so I figured that it should be good enough. Even though the amplifier is a ver y important part of the STM electronics, its circuit is one of the most simplest, which is why I would not have trouble going straight into ordering "real" PCBs.

Good luck with you project and I'm very interested in how your STM will look like and perform :) Also I'm very happy to further discuss 👍

Cheers
Jost

umartechboy, 2024-02-13:
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

danielreda, 2024-02-20:
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

I would also be interested to see if you can get a scan. How long did this take you to build? Approximately how much would it cost to reproduce this instrument?

Daniel

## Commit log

2019-08-25 Mechanics ready
    [0905-0-15-20-75-14-11-0.FCStd, 0905-0-15-20-75-14-11-0.step, 0905-0-15-20-75-14-11-0.stl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]
2019-09-21 Supply board and tunneling amp finished
    [ADC.sch, DAC.sch, Mainboard.kicad_pcb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]
2020-05-24 Many changes. I lost track of them...
    [ADC.sch, Beaglebone.sch, DAC.sch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]
2020-05-25 Layout of piezo DACs ready
    [ADC.sch, Beaglebone.sch, Bias-DAC.sch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]
2020-05-25 ADC Schematic
    [ADC.sch, Mainboard.kicad_pcb, Mainboard.sch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]
2020-05-28 Reference schematic
    [ADC.sch, Beaglebone.sch, Mainboard.kicad_pcb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]
2020-05-28 Layout progress
    [Mainboard.kicad_pcb, Power.sch, Reference.sch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]
2020-06-21 Reference layout finished
    [ADC.sch, Mainboard.kicad_pcb, Mainboard.sch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]
2020-06-21 SPI Connections finished
    [Beaglebone.sch, Mainboard.kicad_pcb, Mainboard.sch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]
2020-06-21 Further layout stuff
    [Mainboard.kicad_pcb, Mainboard.sch]
2020-06-21 Power supply routing progress
    [Mainboard.kicad_pcb, Mainboard.sch, Power.sch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]
2020-06-22 Layout nearly finished
    [Beaglebone.sch, Mainboard.kicad_pcb, Mainboard.sch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]
2020-06-22 Silkscreen rearanged
    [Mainboard.kicad_pcb, Mainboard.sch]
2020-07-14 Mainboard layout and schematic done
    [ADC.sch, Beaglebone.sch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]
2020-07-15 Head interconnect finished
    [ADC_DAC-Selection.ods, Assembly.FCStd, Base-Interconnect.kicad_pcb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]
2020-07-16 Base interconnect and head interconnect in fabrication
    [Assembly.FCStd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]
2020-07-29 Added images
    [ADC.sch, Base-Interconnect.sch, Head-Interconnect.kicad_pcb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]
2020-08-08 Added axial vibration analysis measurement
    [Axial.csv, Axial.ods, axial-setup1.csv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]
2020-08-16 Added tunneling amp frequency response
    [OPA-Selection.ods, freq-response.csv]
2020-10-09 Added sample-bias interconnect and base interconnect V2
    [Base-Interconnect-B_Cu.gbr, Base-Interconnect-B_Mask.gbr, Base-Interconnect-B_SilkS.gbr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]
2020-10-09 Minor changes to cad model
    [Base-Plate.FCStd, Lower-Plate-PCB-Outline.dxf, Lower-Plate.FCStd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]
2021-04-03 Added i2c address to mainboard lm75
    [Mainboard.sch]
2021-05-17 Added piezo press plate
    [Piezo-Press-Plate.FCStd, Piezo-Press-Plate.stl, Scanning-Head-Assembly.FCStd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]
2021-06-16 Added minor documentation
    [Motor-Adapter.FCStd, Motor-Adapter.stl, Motor-Axle-Adapter.FCStd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]
2021-08-02 Added value to R3 on head interconnect
    [Head-Interconnect.kicad_pcb, Head-Interconnect.sch]
2021-08-02 Clearified warning in DAC op wiring
    [Piezo-DACs.sch]
2021-08-02 Fixed values in schematic
    [Supply-Board.kicad_pcb, Supply-Board.sch, Tunnelling-Amp.kicad_pcb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]
